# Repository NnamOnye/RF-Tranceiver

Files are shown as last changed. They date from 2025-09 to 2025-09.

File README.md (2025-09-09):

# RF-Transceiver on 2.4GHz
# i utilized Interference Management, when developing the microstrip.
# i also utilized impedance matching,and ground zones for noise reduction.
# This design can be used as a receiver and transmitter depending on your application.
# The B.O.M in Production has the components i used.
# Designed Using Kicad ECAD
# KiCAD Download --> https://www.kicad.org/download/

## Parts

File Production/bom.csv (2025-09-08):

Designator | Footprint | Quantity | Value | LCSC Part #
C1, C10 | Decoup_Capacitor_0_1uF | 2 | 0.1uF
C2, C3, C4, C5, C6, C7, C9 | Capacitor10uF | 7 | 10uF
C8 | Capacitor_1_2pF | 1 | 1.2 pF
D1 | LED_SML_D12M1WT86 | 1 | LED
GND1, RX1, TX1, VCC1 | Via_Pad | 4 | ~
J1 | U.FL_R_SMT_01 | 1 | U.FL-R-SMT_01_
R1,R3 | 10kResist | 2 | 10k_Resist
R2 | 1kResist | 1 | 1KOhms
SW1 | boot_button1 | 1 | Button
U1 | ESP32_PICO_D4 | 1 | ESP32-PICO-D4
U2 | SX1280IMLTRT | 1 | SX1280IMLTRT
U3 | LDO_3v_500mA | 1 | LDO
Y1 | Crysta_RF_40MHz | 1 | Crystal
L2 | LQW15AN3N3G8ZD | 1 | Inductor_3.3nH

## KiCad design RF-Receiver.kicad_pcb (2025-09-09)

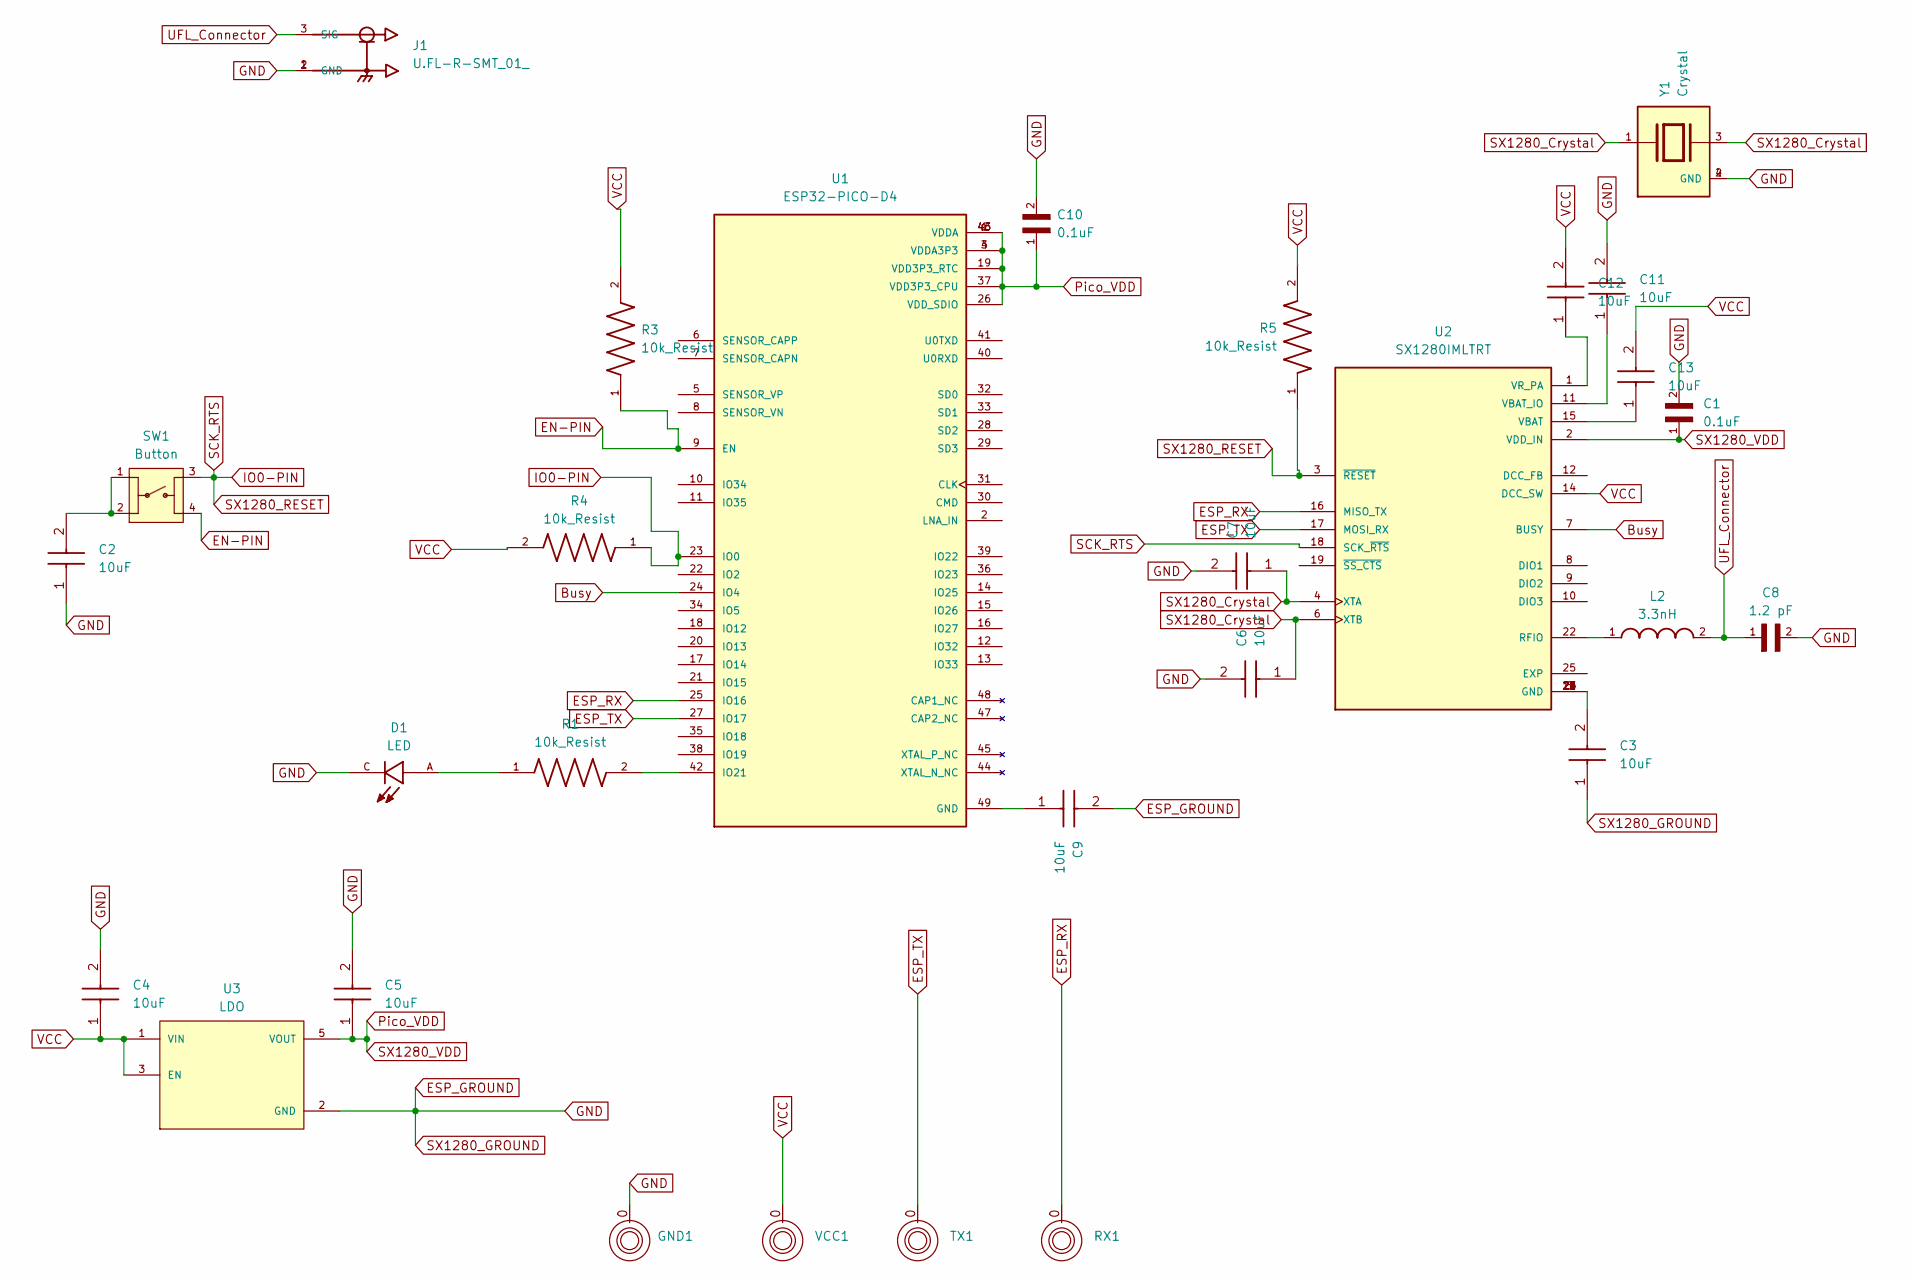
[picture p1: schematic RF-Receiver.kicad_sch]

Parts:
C1, C10: 0.1uF; Decoup_Capacitor_0_1uF
C2, C3, C4, C5, C6, C7, C9, C11, C12, C13: 10uF; Capacitor10uF; Manufacturer_Part_Number C1608X7R1A106M080AT; Mouser Part Number 810-C1608X7R1A106M08
C8: 1.2 pF; Capacitor_1_2pF
D1: LED; LED_SML_D12M1WT86; PARTREV 007
GND1: Via_Pad
J1: U.FL-R-SMT_01_; U.FL_R_SMT_01
L2: 3.3nH; Inductor_3_3nH
R1, R3, R4, R5: 10k_Resist; 10kResist; PARTREV 3/1/2020
RX1: Via_Pad
SW1: Button; boot_button1; PARTREV V
TX1: Via_Pad
U1: ESP32-PICO-D4; ESP32_PICO_D4; PARTREV v1.9
U2: SX1280IMLTRT; PARTREV 3.3
U3: LDO; LDO_3v_500mA; PARTREV B
VCC1: Via_Pad
Y1: Crystal; Crysta_RF_40MHz; PARTREV N/A

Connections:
Busy: U1.24 (IO4), U2.7 (BUSY)
EN-PIN: R3.1, SW1.4, U1.9 (EN)
ESP_GROUND: C1.2, C2.1, C3.1, C4.2, C5.2, C6.2, C7.2, C8.2, C9.2, C10.2, C11.2, D1.C, GND1.0, J1.1 (GND), J1.2 (GND), U3.2 (GND), Y1.2 (GND), Y1.4 (GND)
ESP_RX: RX1.0, U1.25 (IO16), U2.16 (MISO_TX)
ESP_TX: TX1.0, U1.27 (IO17), U2.17 (MOSI_RX)
IO0-PIN: R4.1, R5.1, SW1.3, U1.23 (IO0), U2.3 (~RESET), U2.18 (SCK_~RTS)
unnamed: C2.2, SW1.1, SW1.2
unnamed: C3.2, U2.5 (GND), U2.13 (GND), U2.20 (GND), U2.21 (GND), U2.23 (GND), U2.24 (GND)
unnamed: D1.A, R1.1
unnamed: C9.1, U1.49 (GND)
unnamed: R1.2, U1.42 (IO21)
unnamed: L2.1, U2.22 (RFIO)
unnamed: C13.1, U2.15 (VBAT)
unnamed: C11.1, U2.11 (VBAT_IO)
unnamed: C12.1, U2.1 (VR_PA)
Pico_VDD: C1.1, C5.1, C10.1, U1.1 (VDDA), U1.3 (VDDA3P3), U1.4 (VDDA3P3), U1.19 (VDD3P3_RTC), U1.26 (VDD_SDIO), U1.37 (VDD3P3_CPU), U1.43 (VDDA), U1.46 (VDDA), U2.2 (VDD_IN), U3.5 (VOUT)
SX1280_Crystal: C6.1, C7.1, U2.4 (XTA), U2.6 (XTB), Y1.1, Y1.3
UFL_Connector: C8.1, J1.3 (SIG), L2.2
VCC: C4.1, C12.2, C13.2, R3.2, R4.2, R5.2, U2.14 (DCC_SW), U3.1 (VIN), U3.3 (EN), VCC1.0

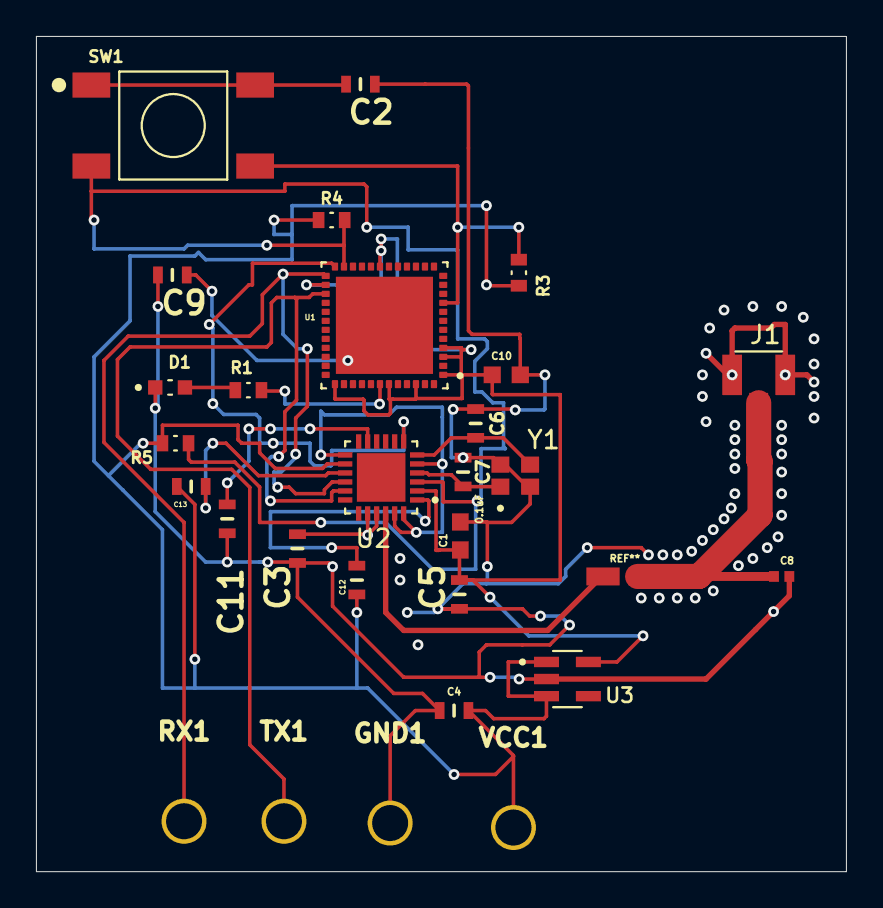
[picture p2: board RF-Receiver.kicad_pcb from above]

Board: 2 copper layers, 45.0 x 46.4 mm, 28 parts (0 on the bottom side), 18 nets.

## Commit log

2025-07-18 Update and rename positions.csv to Production/positions.csv
    [positions.csv]
2025-07-31 Schematic Screenshot
2025-08-12 RF-Receiver Board
2025-09-08 Project files
    Problem: EN Pin floating causing "no power" issue
    Fix: Tied EN Pin to 10KOhm Resistor and VDD
    [RF-Receiver.kicad_pcb, RF-Receiver.kicad_sch]
2025-09-08 Project Files
    Update to board and schematic
    [RF-Receiver.kicad_pcb, RF-Receiver.kicad_sch]
2025-09-09 Updated Design Addressing No Power Up
    Updated Design Addressing no power up during uart to usb flashing
    [designators.csv, positions.csv]
